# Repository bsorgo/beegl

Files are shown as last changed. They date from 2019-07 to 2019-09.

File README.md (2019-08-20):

# BeeGl

Beehive monitoring system based on _ESP32 based boards_ and _Node Red_.  Main system application is beehive monitoring but can be used also as weather station.

# Main features

- Measures weight, temperature and humidity 
- Outbound communication through WiFi and GPRS (2G)
- Inbound communication using WiFi and Bluetooth (BLE)
- Web based management API - Web GUI and rest
- Pull/push OTA and setting updates
- Node operational time frame rules and power management
- Forms a distributed system where source and broker nodes can be linked together
- Basic server capable of displaying realtime data and statistics



If you like **BeeGl**, give it a star, or fork it and contribute! If you find this system useful please 

## Quick Install

- Broker Device - [README.md](esp32/beegl_broker/README.md)
- Server [README.md](https://github.com/bsorgo/beegl_server)

## Libraries Used

### Broker component

- [ArduinoHTTPClient](https://github.com/arduino-libraries/ArduinoHttpClient) - forked (https://github.com/bsorgo/ArduinoHttpClient) - pending fixes for ESP32 environment
- [ArduinoJson](https://github.com/bblanchon/ArduinoJson)
- [AsyncTcp](https://github.com/me-no-dev/AsyncTCP)
- [DHT sensor library for ESPx](https://github.com/beegee-tokyo/DHTesp)
- [ESP Async WebServer](https://github.com/me-no-dev/ESPAsyncWebServer)
- [HX711](https://github.com/bogde/HX711)
- [PubSubClient](https://github.com/knolleary/pubsubclient)
- [Time](https://github.com/PaulStoffregen/Time) - forked (https://github.com/bsorgo/Time) 
- [Timezone](https://github.com/JChristensen/Timezone)
- [TinyGSM](https://github.com/vshymanskyy)

### Server components

- [Mosquitto](https://mosquitto.org/)
- [Node Red](https://nodered.org/)
- [Node Red Dashboard](https://flows.nodered.org/node/node-red-dashboard)

## License

This program is licensed under GPL-3.0

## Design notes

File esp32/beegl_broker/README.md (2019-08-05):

# BeeGl ESP32 Source/Broker 

## Installing / Getting started

### Hardware
 1. Assemble 
   - build broker /source node device using instructions [BeeGl Beehive Monitoring](https://www.thingiverse.com/thing:3718552) or
   - assemble components on test board using ESP32 board of your choice following [BeeGl Broker/Source Node Schematic](https://thingiverse-production-new.s3.amazonaws.com/assets/a2/c6/a6/41/1a/BeeGl_Broker_rev_1.0.png) or
   - just use any ESP32 board with at least 4MB of flash without components just to play with app
 2. Connect device to serial port using appropriate wiring
### Software
#### From source
 1. Clone repository: git clone https://github.com/bsorgo/beegl.git
 2. Install Platform.IO IDE [PlatformIO IDE](https://platformio.org/platformio-ide?utm_source=github&utm_medium=arduino-esp32)
 3. Run Platform.IO and install Espressif 32 Platform
 4. Open Folder which represents local path of esp32/platformio/beegl_broker
 5. Modify platform.ini [configuration](https://docs.platformio.org/en/latest/platforms/espressif32.html#configuration) `[env:esp32dev]`, `[env:env:lolin_d32_pro_16mb]` 
    or create a new one. In particular `monitor_port` and  `upload_port`should be changed to match assigned local COM port
```
[env:esp32dev_sim800_spiffs]
platform = espressif32
lib_deps = ${common.lib_deps}
board = esp32dev
framework = arduino
board_build.partitions = customparts_tight.csv
upload_port = COM10
monitor_port = COM10
monitor_speed = 115200
build_flags = 
    -DCOMPONENT_EMBED_TXTFILES=src/index.html 
    -DCORE_DEBUG_LEVEL=5
    -DTINY_GSM_MODEM_SIM800
    -DMAX_LOG_FILES=5
    -DMAX_LOG_FILE_SIZE=65536
    -DMQTT_MAX_PACKET_SIZE=512
    -DSYSTEM_VARIANT=\"esp32dev_sim800_spiffs\"
    -DMAX_BACKLOG=200
    -DVER=\"1.1.0\"
```
  6. Upload 
  7. Examine serial output using Monitor 

#### Development/Stable releases

Check [Releases](http://www.github.com/bsorgo/beegl/releases/)

## Runtime

### First run/safe/maintenance mode

At first run or when startup sequence is interrupted by hardware reset/error, device will terminate in safe/maintenance mode. Also indicated by continious red LED. In this case all outbound connections are disabled (WiFi, GPRS) and WiFi access point with SSID: BEE000 and password: 123456789 is brought up. 

Using WiFi capable mobile device establish a connection with SSID named BEE000. 

With web browser on device navigate to http://192.168.4.1 - BeeGl Broker settings page.

The serial output should look something like this:

```
[I][Connection.cpp:133] wifiSetup(): [WIFI] AP started
[I][Connection.cpp:134] wifiSetup(): [WIFI] AP IP: 192.168.4.1
[D][WiFiGeneric.cpp:336] _eventCallback(): Event: 13 - AP_START
[I][Connection.cpp:135] wifiSetup(): [WIFI] AP password: 123456789
[I][Connection.cpp:44] modemOff(): [GSM] OFF
[I][Service.cpp:27] webServerSetup(): [WEB Server] Starting web server
[I][Service.cpp:33] webServerSetup(): [WEB Server] Web server started
[D][Runtime.cpp:223] setSafeModeOnRestart(): [ESP32] Open done
[D][Runtime.cpp:233] setSafeModeOnRestart(): [ESP32] Write fdone.
[D][Runtime.cpp:243] setSafeModeOnRestart(): [ESP32] Commit done.
[I][main.cpp:128] setup(): ***************************************
[I][main.cpp:129] setup(): ******** SAFE/MAINTENANCE MODE ********
[I][main.cpp:130] setup(): ***************************************
[I][main.cpp:131] setup(): Use Wifi device, connect to SSID:BEE000. By using web browser navigate to http://192.168.4.1
```

Note:

On some Android phones mobile data should be disabled when connected to non-internet AP.

### Operational mode

It's normal broker/source node mode. At startup setup sequence is executed:

1. Mount FS filesystem - 1 green LED blink
2. Read config file - 2 green LED blinks
3. Establish inbound/outbound connection and services (web server) - 3 blinks
4. Initiate publisher, sensors and broker - 4 blinks

After setup sequence green LED lights continiously. If any of above steps fails the device goes to deep sleep or safe/maintanance mode.
In addition updates are checked between step 3 and 4 if set accordingly in time interval/frame definition (`"upd" : "true"`)

During main program loop:

- Measurements are performed (weight & temp/humidity)
- Publish measurement to central server
- Check operational time frame and put device in deep sleep

```
[I][Runtime.cpp:41] initialize(): [ESP] Firmware version 1.4
[D][Runtime.cpp:181] getSafeModeOnRestart(): [ESP32] Open done
[D][Runtime.cpp:188] getSafeModeOnRestart(): [ESP32] Read OK, value: 0
[SPIFFS] Begin FS
[D][Runtime.cpp:223] setSafeModeOnRestart(): [ESP32] Open done
[D][Runtime.cpp:233] setSafeModeOnRestart(): [ESP32] Write fdone.
[D][Runtime.cpp:243] setSafeModeOnRestart(): [ESP32] Commit done.
[I][Runtime.cpp:155] printWakeupReason(): [ESP32] Wakeup was not caused by deep sleep. Reason: 0
[I][main.cpp:136] setup(): [ESP] Device name: BEE007
[I][main.cpp:137] setup(): [ESP] Inbound mode: 0
[I][main.cpp:138] setup(): [ESP] Outbound mode: 1
[I][Connection.cpp:90] wifiSetup(): [WIFI] Settings: Use custom ip: 0, IP: 192.168.4.1 GW: 192.168.4.1 NETMASK: 255.255.255.0
[I][Connection.cpp:91] wifiSetup(): [WIFI] APSettings: IP: 192.168.4.1 GW: 0.0.0.0 NETMASK: 255.255.255.0
[I][Connection.cpp:139] wifiSetup(): [WIFI] Starting STA
[I][Connection.cpp:140] wifiSetup(): [WIFI] Outbound connecting to MyWifi
[D][WiFiGeneric.cpp:336] _eventCallback(): Event: 0 - WIFI_READY
[D][WiFiGeneric.cpp:336] _eventCallback(): Event: 2 - STA_START
[D][WiFiGeneric.cpp:336] _eventCallback(): Event: 4 - STA_CONNECTED
[D][WiFiGeneric.cpp:336] _eventCallback(): Event: 7 - STA_GOT_IP
[D][WiFiGeneric.cpp:379] _eventCallback(): STA IP: 192.168.0.163, MASK: 255.255.255.0, GW: 192.168.0.1
[I][Connection.cpp:160] wifiSetup(): [WIFI] connected
[I][Connection.cpp:161] wifiSetup(): [WIFI] IP: 192.168.0.163
[I][Connection.cpp:44] modemOff(): [GSM] OFF
[I][Service.cpp:27] webServerSetup(): [WEB Server] Starting web server
[I][Service.cpp:33] webServerSetup(): [WEB Server] Web server started
[D][Settings.cpp:429] syncTimeAndSettings(): [SETTINGS] Time and setting prefix: www.allium4.com/beegl/
[D][Settings.cpp:434] syncTimeAndSettings(): [SETTINGS] Hostname: www.allium4.com
[D][Settings.cpp:435] syncTimeAndSettings(): [SETTINGS] Path: /beegl/v1/devices/BEE007
[D][Settings.cpp:436] syncTimeAndSettings(): [SETTINGS] Username: bee
[I][Settings.cpp:454] readTimeAndSettings(): [SETTINGS] Response code from server: 200
[I][Settings.cpp:464] readTimeAndSettings(): [SETTINGS] Header date string: Mon, 01 Jul 2019 18:05:21 GMT
[D][Settings.cpp:498] readTimeAndSettings(): [SETTINGS] Time fractions: 2019-07-01T18:05:21.000Z
[D][Settings.cpp:751] getCurrentSchedulerEntry(): [SCHEDULER] Current entry: 7;20:0,20:10;0
[D][Settings.cpp:751] getCurrentSchedulerEntry(): [SCHEDULER] Current entry: 7;20:0,20:10;0
[I][MqttPublisher.cpp:25] setup(): [MQTT] Setup
[I][MqttPublisher.cpp:36] setup(): [MQTT] Server: internalMqttServer
[I][MqttPublisher.cpp:37] setup(): [MQTT] Server: mqtt.allium4.com, port 1883
[I][Measurer.cpp:64] scaleSetup(): [HX711] Setup
[I][Measurer.cpp:65] scaleSetup(): [HX711] Scale factor: -23.209999
[I][Measurer.cpp:66] scaleSetup(): [HX711] Scale offset: 1828191
[I][Measurer.cpp:67] scaleSetup(): [HX711] Scale unit: g
[I][Measurer.cpp:79] dhtSetup(): [DHT] Setup
[D][Runtime.cpp:223] setSafeModeOnRestart(): [ESP32] Open done
[D][Runtime.cpp:233] setSafeModeOnRestart(): [ESP32] Write fdone.
[D][Runtime.cpp:243] setSafeModeOnRestart(): [ESP32] Commit done.
[D][Measurer.cpp:116] measure(): [HX711] Powerup
[D][Measurer.cpp:122] measure(): [MEASURER] Read weight 23451.12
[D][Measurer.cpp:123] measure(): [HX711] Shutdown
[D][Measurer.cpp:131] measure(): [MEASURER] Read temperature and humidity: 23.5 C 65 %
[D][Publisher.cpp:60] storeMessage(): [STORE] Message
[D][MqttPublisher.cpp:74] reconnect(): [MQTTPUBLISHER] Client: BEE007-20, username: bee
[D][MqttPublisher.cpp:77] reconnect(): [MQTTPUBLISHER] Connected.
{"id":"BEE007","time":"2019-07-01T20:05:21+02:00","ver":"1.4","whtS":{"w":23451.12,"u":"g"},"tmpS":{"t":23.5,"u":"C"},"humS":{"h":65,"u":"pct"}}
[D][MqttPublisher.cpp:50] publishMessage(): [MQTTPUBLISHER] scale_sensors
[D][MqttPublisher.cpp:51] publishMessage():
[E][MqttPublisher.cpp:59] publishMessage(): [MQTTPUBLISHER] Publish OK
```

### Settings

Settings can be managed:

- Using web interface on http: `'http://<device ip>`
- Using rest api GET/POST `'http://<device ip>/rest/settings'`



#### Basic settings

1. Device name - Unique device name 
2. Outbound mode. Defines upstream communication preference. For broker node this sets communication with internet/intranet towards central server. For source node this defines communication channel with broker node.
  - Select WiFi if outbound communication is WiFi. Specify Outbound WiFi Settings (SSID, Password and IP related settings)
  - Select GPRS for GPRS communication. Specify Outbound GSM/GPRS Settings (APN, Username and Password). Needles to say SIM card should be inserted in SIM module. These settings are GSM G2 network operator specific. 
3. Setting URL prefix defines central server url in format `<hostname or ip>/<path>/`. Example `192.168.0.250/beegl/`. Currently only http on port 80 is supported. Provide also username and password for basic authentication if required
4. Publisher settings
  - Select MQTT if publisher uses MQTT protocol. Measurements are published on `measurements` topic. 
  - Select HTTP to publish over HTTP. Path is concatenated using Setting URL Prefix and `v1/measurements` path fraction. For example if setting URL prefix is `192.168.0.250/beegl/` measurements resource measurement url is will be published on `192.168.0.250/beegl/v1/measurements`.
 5. MQTT Settings set upstream MQTT server connection parameters
   - Internal server address - MQTT server IP or hostname when outbound connection is WiFi. 
   - External server address - MQTT server IP or hostname when outbound connection is GPRS.
   - Port (TCP Port Number) - MQTT server port. Default port is 1883.
   - Username and password - MQTT server username an password
   Please note MQTT SSL/TLS connections are not supported.
6. Operational Time Intervals are used to define time frames when broker/source node will wake up from deep sleep to operational mode. Specify hour interval From and To in format `hh:mm`. Up to 10 intervals can be specified. Recurring intervals (e.g. wake up every 10 minutes) are not yet supported.

#### Measurement settings
 
 1. Measurer settings:
   - Measure weight (Yes/No)
   - Measure temperature and humidity (Yes/No)
 2. Scale settings
   - Factor (Decimal  number) - a calibration factor
   - Offset (Whole number) - calibration offset. By pressing button __Tare__ this value is determined based on current load. 
   __Measure weight__ button does weight measurement with current calibration factor and offset

 #### Advanced settings
 
1. Inbound mode. Provides inbound channels for other source nodes - when device act as broker:

- None - No inbound connection available
- WiFi - AP Wifi is initiated. Source nodes can connect on broker AP and publish settings based on source node Setting URL prefix to path  `<hostname or ip>/<path>/v1/measurements`
- Bluetooth(BLE) - BT radio and BLE service is established. Used for BLE source nodes. This funcitonality is still under heavy development
- WiFi+Bluetooth(BLE) - both AP WiFi and BLE service are established

2. Refresh (Milliseconds) - refresh interval for measures and publishes. Default 60000 (1 minute).
3. Time settings (Timezone selector). Sets standard and summer timezones.

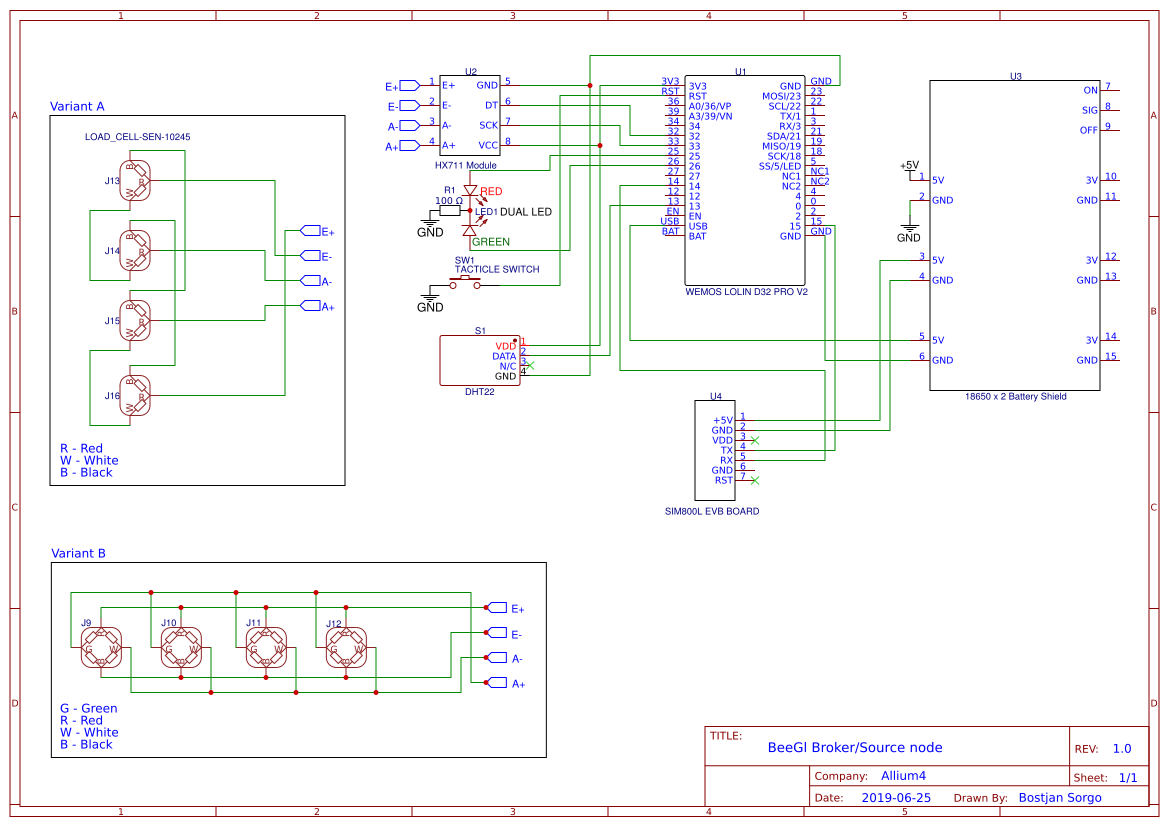
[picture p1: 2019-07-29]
hw/schematic/BeeGl_Broker_LolinD32Pro_SIM800L_rev_1.0.png

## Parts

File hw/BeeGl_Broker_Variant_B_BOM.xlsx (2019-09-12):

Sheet: Info
Name | BeeGL Broker Variant B BOM Rev 1.0
Sheets
LolinD32-ESP32 | Bill of material for Lolin D32 ProESP32 board & SIM800L 3G GSM/GPRS module part. Used only for Wifi Outbound/Inbound Communication
LolinD32-ESP32-SIM800L | Bill of material for Lolin D32 Pro ESP32 board 3G GSM/GPRS module part. Used for GSM or/and Wifi Outbound/Inbound Communication
Load Cells Frame | Bill of material for load sensor frame
Supplemental material
 | Instant glue (Superglue, Loctite, Gorilla,…) to assemble plastic parts together
 | Solder & solder paste to connect wires/components/connectors
Release notes
2019-08-28 | Initial release

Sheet: LolinD32-ESP32
ID | Component came | Designator | Quantity | Unit | More info/Query | Note
1 | WEMOS LOLIN D32 PRO V2 | U1 | 1 | pcs | https://wiki.wemos.cc/products:d32:d32_pro
2 | HX711 Module | U2 | 1 | pcs | https://www.google.com/search?q=hx711+module https://www.sparkfun.com/products/13879 https://www.aliexpress.com/wholesale?catId=0&initiative_id=SB_20190705010449&SearchText=hx711
3 | 18650 x 2 Battery Shield | U3 | 1 | pcs | https://www.aliexpress.com/wholesale?catId=0&initiative_id=SB_20190705011301&SearchText=battery+shield
4 | DHT22 | S1 | 1 | pcs | https://www.google.com/search?q=dht22
5 | DUAL LED | LED1 | 1 | pcs | https://www.google.com/search?q=dual+led+3mm+green+red
6 | 100 Ω | R1 | 1 | pcs
7 | TACTICLE SWITCH | SW1 | 1 | pcs | https://www.google.com/search?q=tacticle+switch
8 | Heat shrink tube 1.5 mm (1/16) |  | 1 | m | Used for cable to cable or cable to component contacts
9 | Heat shrink tube 1.5 mm (1/8) |  | 1 | m | Used for cable to cable or cable to component contacts
10 | Heat shrink tube 1.5 mm (1/4) |  | 1 | m | Used for cable to cable or cable to component contacts
11 | Dupont 1P 10 cm Female to Female |  | 20 | pcs | https://www.google.com/search?q=dupont+female+to+female+10+cm&oq=dupont+female+to+female+10+cm
12 | Nylon M3 6mm stadoff with screw |  | 6 | pcs | https://www.google.com/search?q=M3+Nylon+screw+standoff
13 | 18650 2000mAh Battery |  | 2 | pcs
14 | M5x20 Hexagon socket Head Cap Screw |  | 2 | pcs | ISO 4762, A2 Stainless steel, Hexagon/Torx socket head cap screw, k=5mm, l=20mm http://www.fasteners.eu/standards/ISO/4762
15 | M5x10 Hexagon socket Head Cap Screw |  | 2 | pcs | ISO 4762, A2 Stainless steel, Hexagon/Torx socket head cap screw, k=5mm, l=10mm http://www.fasteners.eu/standards/ISO/4762
16 | M5 Hexagon Nut |  | 4 | pcs | ISO 4032, A2 Stainless steel Hexagon nut, m=~4.5, s=8 http://www.fasteners.eu/standards/ISO/4032
17 | Pre/Post paid subscirpiton Micro SIM - 2G/GPRS Data Eligible |  | 1 | pcs
18 | Lolin D 32 Pro Case |  | 1 | pcs | 3D printed beegl_broker_variant_B_lolind32pro_dual_18650_case.stl | Recommended ASA material, >40% infill density
19 | Case cover |  | 1 | pcs | 3D printed beegl_broker_case_cover_no_holes.stl | Recommended ASA material, >60% infill density
20 | Mounting panel |  | 1 | pcs | 3D printed beegl_broker_mounting_panel.stl | Recommended ASA material, >60% infill density
21 | Solar panel holder broker case mount |  | 1 | pcs | 3D printed beegl_broker_solar_panel_holder_beegl_broker_mount.stl | Recommended ASA material, >60% infill density
22 | Solar panel holder solar panel mount |  | 1 | pcs | 3D printed beegl_broker_solar_panel_holder_solar_panel_mount.stl | Recommended ASA material, >60% infill density
23 | 5V USB Solar panel |  | 1 | pcs | Solar panel, output voltage 5V, USB female connector and at least 5W. https://www.aliexpress.com/item/33023060443.html
24 | Micro usb cable |  | 1 | pcs | 20 or 30 cm usb cable (depends on solar panel model)

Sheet: LolinD32-ESP32-SIM800L
ID | Component came | Designator | Quantity | Unit | More info/Query | Note
1 | WEMOS LOLIN D32 PRO V2 | U1 | 1 | pcs | https://wiki.wemos.cc/products:d32:d32_pro
2 | HX711 Module | U2 | 1 | pcs | https://www.google.com/search?q=hx711+module https://www.sparkfun.com/products/13879 https://www.aliexpress.com/wholesale?catId=0&initiative_id=SB_20190705010449&SearchText=hx711
3 | 18650 x 2 Battery Shield | U3 | 1 | pcs | https://www.aliexpress.com/wholesale?catId=0&initiative_id=SB_20190705011301&SearchText=battery+shield
4 | DHT22 | S1 | 1 | pcs | https://www.google.com/search?q=dht22
5 | DUAL LED | LED1 | 1 | pcs | https://www.google.com/search?q=dual+led+3mm+green+red
6 | 100 Ω | R1 | 1 | pcs
7 | TACTICLE SWITCH | SW1 | 1 | pcs | https://www.google.com/search?q=tacticle+switch
8 | Heat shrink tube 1.5 mm (1/16) |  | 1 | m | Used for cable to cable or cable to component contacts
9 | Heat shrink tube 1.5 mm (1/8) |  | 1 | m | Used for cable to cable or cable to component contacts
10 | Heat shrink tube 1.5 mm (1/4) |  | 1 | m | Used for cable to cable or cable to component contacts
11 | Dupont 1P 10 cm Female to Female |  | 20 | pcs | https://www.google.com/search?q=dupont+female+to+female+10+cm&oq=dupont+female+to+female+10+cm
12 | Nylon M3 6mm stadoff with screw |  | 6 | pcs | https://www.google.com/search?q=M3+Nylon+screw+standoff
13 | 18650 2000mAh Battery |  | 2 | pcs
14 | M5x20 Hexagon socket Head Cap Screw |  | 2 | pcs | ISO 4762, A2 Stainless steel, Hexagon/Torx socket head cap screw, k=5mm, l=20mm http://www.fasteners.eu/standards/ISO/4762
15 | M5x10 Hexagon socket Head Cap Screw |  | 2 | pcs | ISO 4762, A2 Stainless steel, Hexagon/Torx socket head cap screw, k=5mm, l=10mm http://www.fasteners.eu/standards/ISO/4762
16 | M5 Hexagon Nut |  | 4 | pcs | ISO 4032, A2 Stainless steel Hexagon nut, m=~4.5, s=8 http://www.fasteners.eu/standards/ISO/4032
17 | Pre/Post paid subscirpiton Micro SIM - 2G/GPRS Data Eligible |  | 1 | pcs
18 | Lolin D 32 Pro and SIM800L Case |  | 1 | pcs | 3D printed beegl_broker_variant_B_lolind32pro_sim800l_dual_18650_case.stl | Recommended ASA material, >40% infill density
19 | Case cover |  | 1 | pcs | 3D printed beegl_broker_case_cover_no_holes.stl | Recommended ASA material, >60% infill density
20 | Mounting panel |  | 1 | pcs | 3D printed beegl_broker_mounting_panel.stl | Recommended ASA material, >60% infill density
21 | Solar panel holder broker case mount |  | 1 | pcs | 3D printed beegl_broker_solar_panel_holder_beegl_broker_mount.stl | Recommended ASA material, >60% infill density
22 | Solar panel holder solar panel mount |  | 1 | pcs | 3D printed beegl_broker_solar_panel_holder_solar_panel_mount.stl | Recommended ASA material, >60% infill density
23 | SIM800L EVB BOARD | U4 | 1 | pcs | https://www.google.com/search?q=sim800l+v2.0 https://www.aliexpress.com/wholesale?SearchText=sim800l+v2.0
24 | Nylon M3 10mm stadoff with screw |  | 2 | pcs | https://www.google.com/search?q=M3+Nylon+screw+standoff
25 | GSM antena |  | 1 | pcs | 868/915/1800/1900 MHz SMA Male antenna 2, 3 or 5 DBI. To choose depending on signal strenght & local compliancy. With SMA male connector.
26 | GSM antenna SMA to U-FL cable 10 cm |  | 1 | pcs | SMA female to U.FL connector 10 cm https://www.google.com/search?q=SMA+to+U.FL
26 | 5V USB Solar panel |  | 1 | pcs | Solar panel, output voltage 5V, USB female connector and at least 5W. https://www.aliexpress.com/item/33023060443.html
27 | Micro usb cable |  | 1 | pcs | 20 or 30 cm usb cable (depends on solar panel USB connector distance)

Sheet: Load Cells Frame
ID | Component came | Designator | Quantity | Unit | More info/Query | Note
1 | AlMgSi 20x20x2 U-Profile B1 |  | 2 | pcs | BeeGl_Broker_VariantB_Drawings_rev_1.1.pdf
2 | AlMgSi 20x20x2 U-Profile A1 |  | 1 | pcs | BeeGl_Broker_VariantB_Drawings_rev_1.1.pdf
3 | AlMgSi 20x20x2 U-Profile A2 |  | 1 | pcs | BeeGl_Broker_VariantB_Drawings_rev_1.1.pdf
4 | Straight Bar Load Cell Bottom Edge |  | 4 | pcs | 3D printed beegl_broker_variant_B_almgsi_20x20x2_straight_bar_load_cell_bottom_edge.stl | Recommended ASA material, >60% infill density
5 | Straight Bar Load Cell Top Edge |  | 4 | pcs | 3D printed beegl_broker_variant_B_almgsi_20x20x2_straight_bar_load_cell_top_edge.stl (https://www.google.com/search?q=dht22) | Recommended ASA material, >60% infill density
6 | Straight Bar Load Cell Base |  | 1 | pcs | 3D printed beegl_broker_variant_B_almgsi_20x20x2_straight_bar_load_cell_base.stl (https://www.google.com/search?q=dual+led+3mm+green+red) | Recommended ASA material, >60% infill density
7 | Cable align |  | 8 | pcs | 3D printed beegl_broker_variant_B_almgsi_20x20x2_straight_bar_load_cell_cable_align.stl | Recommended ASA material, >60% infill density
8 | M5x20 Countesunk Head Cap Screw |  | 8 | pcs | ISO 10642,A2 Stainless steel, Hexagon/Torx socket countersunk head cap screw, k=5mm, l=20mm http://www.fasteners.eu/standards/ISO/10642
9 | M5x15 Countesunk Head Cap Screw |  | 8 | pcs | ISO 10642,A2 Stainless steel, Hexagon/Torx socket countersunk head cap screw, k=5mm, l=15mm http://www.fasteners.eu/standards/ISO/10642
10 | M4x10 Countesunk Head Cap Screw |  | 10 | pcs | ISO 10642,A2 Stainless steel, Hexagon/Torx socket countersunk head cap screw, k=4mm, l=10mm http://www.fasteners.eu/standards/ISO/10642
11 | M5 Hexagon Nut |  | 8 | pcs | ISO 4032, A2 Stainless steel Hexagon nut M5, m=~4.5, s=8 http://www.fasteners.eu/standards/ISO/4032
12 | M4 Hexagon Nut |  | 2 | pcs | ISO 4032, A2 Stainless steel Hexagon nut M4, m=~4, s=7 http://www.fasteners.eu/standards/ISO/4032
13 | FTP patch cable |  | 2 | m | Soft cable. Outer insulation removed. Only twisted pair wires used to prolong load cell & dht22 wires | Can be replaced with single or twisted pair copper wire/cable of diameter 0.1~0.16mm
14 | LOAD_CEL-20KG | J9,J10,J11,J12 | 4 | pcs | https://www.google.com/search?&q=load+cell+20kg https://www.aliexpress.com/wholesale?catId=0&initiative_id=SB_20190705010547&SearchText=load+cell https://www.banggood.com/search/load-cell.html
15 | 2.54 Pitch 1P Housing with Female Terminal Sockets |  | 10 | pcs | 2.54mm Pitch 1P Dupont Jumper Wire Housing with 50x Female Dupont Terminal Sockets

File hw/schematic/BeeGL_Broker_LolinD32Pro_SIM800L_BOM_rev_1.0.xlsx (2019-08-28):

ID | Name | Designator | Footprint | Quantity | More info/Query | Note
1 | WEMOS LOLIN D32 PRO V2 | U1 | WEMOS_LOLIN_D32_PRO | 1 | https://wiki.wemos.cc/products:d32:d32_pro
2 | HX711 Module | U2 | NONE | 1 | https://www.google.com/search?q=hx711+module https://www.sparkfun.com/products/13879 https://www.aliexpress.com/wholesale?catId=0&initiative_id=SB_20190705010449&SearchText=hx711
3 | 18650 x 2 Battery Shield | U3 | 18650 X 2 BATTERY SHIELD V8 | 1 | https://www.aliexpress.com/wholesale?catId=0&initiative_id=SB_20190705011301&SearchText=battery+shield
4 | SIM800L EVB BOARD | U4 | HDR1X6_SIM800L_BOARD | 1 | https://www.google.com/search?q=sim800l+v2.0 https://www.aliexpress.com/wholesale?SearchText=sim800l+v2.0
5 | DHT22 | S1 | DHT22 | 1 | https://www.google.com/search?q=dht22
6 | DUAL LED | LED1 | LED-3MM_DUAL | 1 | https://www.google.com/search?q=dual+led+3mm+green+red
7 | 100 Ω | R1 | NONE | 1
8 | TACTICLE SWITCH | SW1 | KEY-6.0*6.0-4 | 1 | https://www.google.com/search?q=tacticle+switch
9 | LOAD_CEL-20KG | J9,J10,J11,J12 | 1X03 | 4 | https://www.google.com/search?&q=load+cell+20kg https://www.aliexpress.com/wholesale?catId=0&initiative_id=SB_20190705010547&SearchText=load+cell https://www.banggood.com/search/load-cell.html | Variant B,C
10 | LOAD_CELL-SEN-10245 | J13,J14,J15,J16 | 1X03 | 4 | https://www.google.com/search?&q=load+cell+50kg https://www.sparkfun.com/products/10245 | Variant A

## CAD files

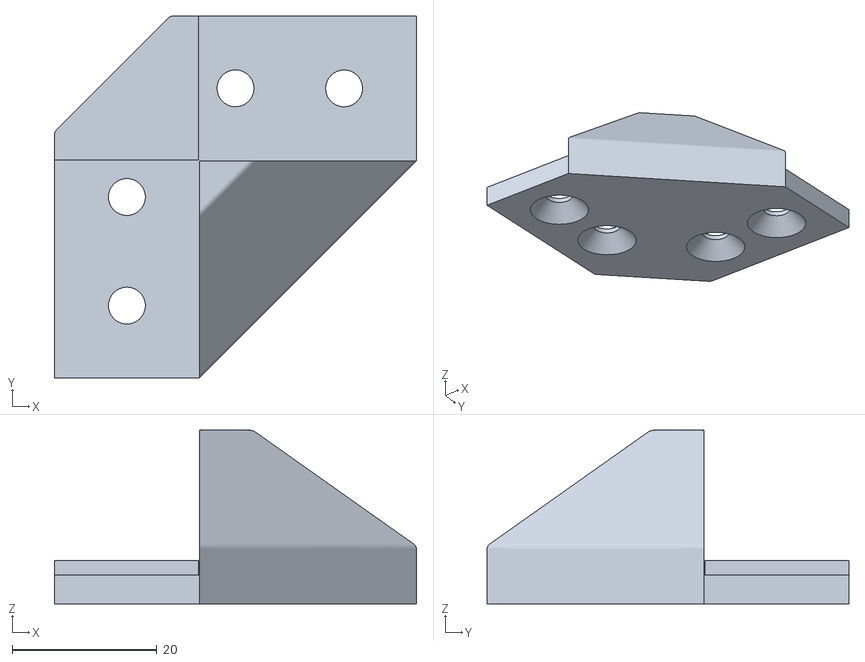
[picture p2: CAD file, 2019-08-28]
hw/3D_models/beegl_broker_variant_B_almgsi_20x20x2_straight_bar_load_cell_top_edge.stl
50.0 x 50.0 x 24.0

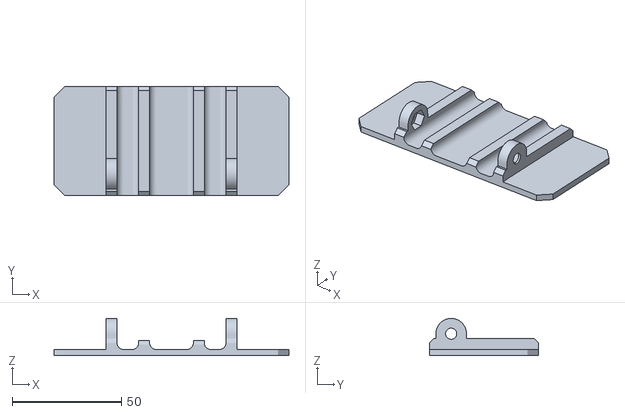
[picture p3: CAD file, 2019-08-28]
hw/3D_models/beegl_broker_solar_panel_holder_solar_panel_mount.stl
107.4 x 50.0 x 17.0

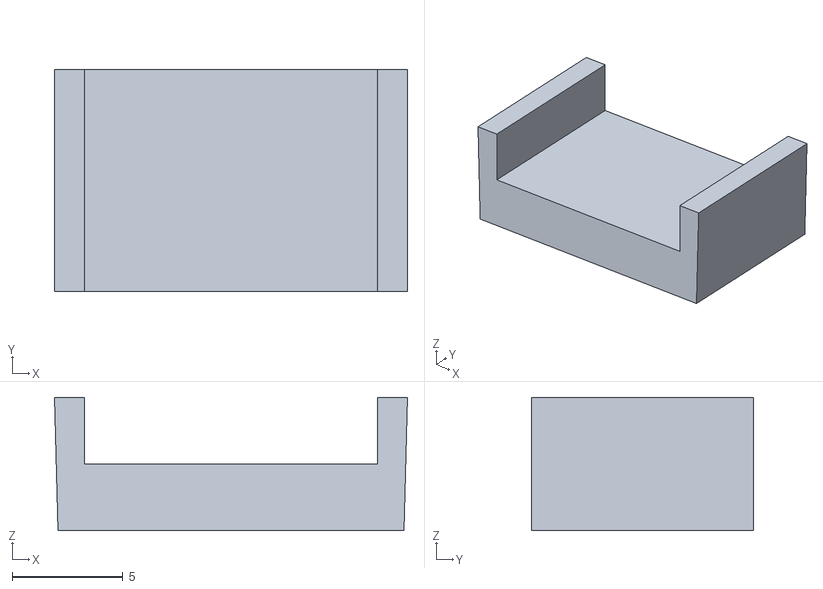
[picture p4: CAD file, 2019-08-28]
hw/3D_models/beegl_broker_variant_B_almgsi_20x20x2_straight_bar_load_cell_cable_align.stl
15.9 x 10.0 x 6.00

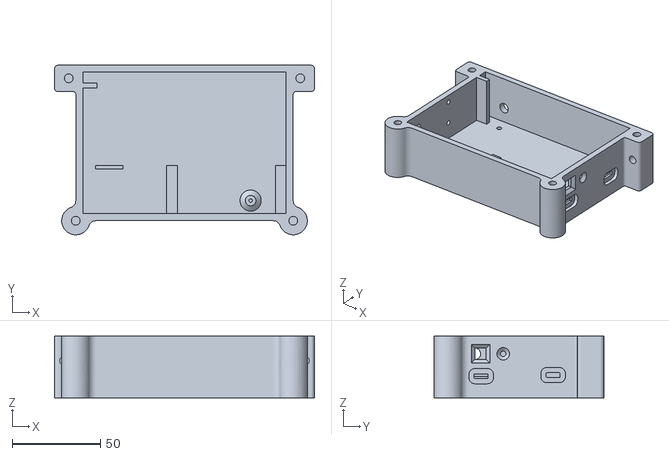
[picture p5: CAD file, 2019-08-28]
hw/3D_models/beegl_broker_variant_B_lolind32pro_sim800l_dual_18650_case.stl
147.1 x 96.0 x 35.0

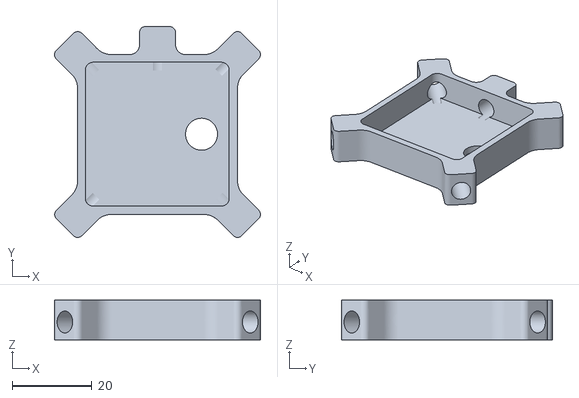
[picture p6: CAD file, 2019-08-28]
hw/3D_models/beegl_broker_variant_A_hx711_dht22_case.stl
51.5 x 52.7 x 10.00

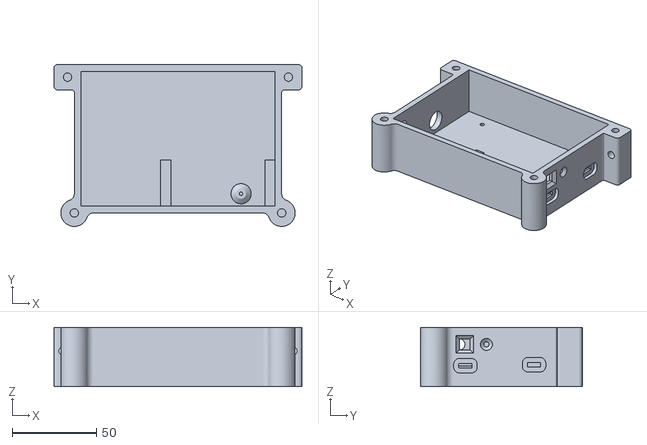
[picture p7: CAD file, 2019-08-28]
hw/3D_models/beegl_broker_variant_AC_lolind32pro_sim800l_dual_18650_case.stl
147.1 x 96.0 x 35.0

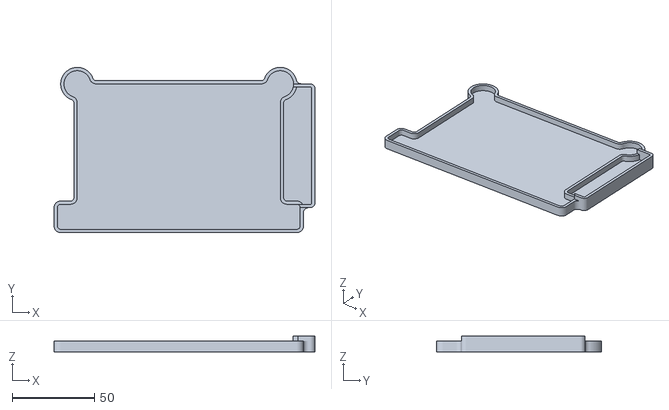
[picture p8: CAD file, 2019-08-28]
hw/3D_models/beegl_broker_case_cover_no_holes.stl
158.2 x 100.2 x 9.40

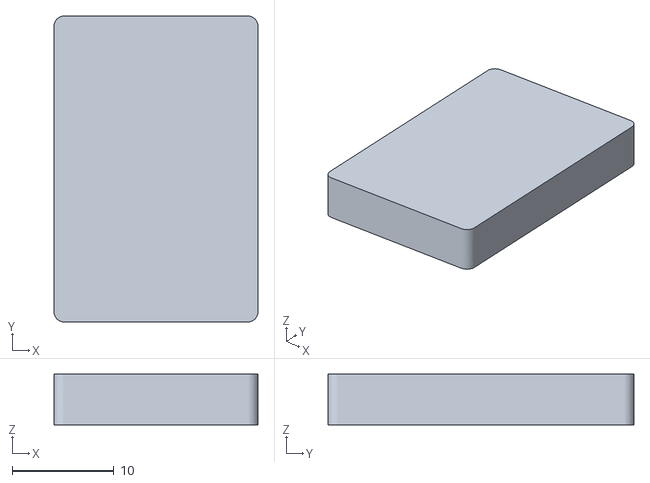
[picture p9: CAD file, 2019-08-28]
hw/3D_models/beegl_broker_variant_BC_almgsi_20x20x2_straight_bar_load_cell_top_dist_wo_holes.stl
20.0 x 30.0 x 5.00

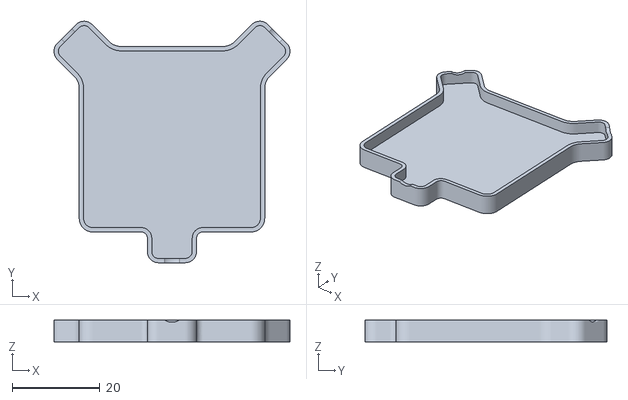
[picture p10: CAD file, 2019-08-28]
hw/3D_models/beegl_broker_variant_C_hx711_dht22_case_cover.stl
53.7 x 54.9 x 5.00

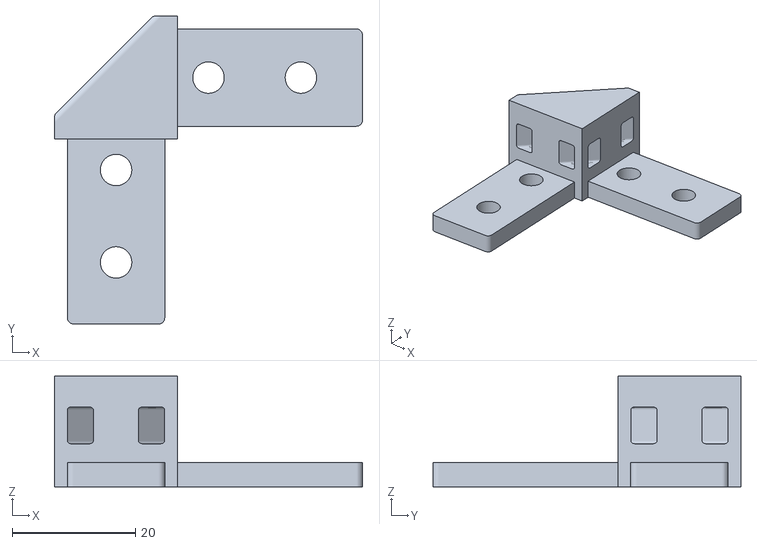
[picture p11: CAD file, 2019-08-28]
hw/3D_models/beegl_broker_variant_B_almgsi_20x20x2_straight_bar_load_cell_bottom_edge.stl
50.0 x 50.0 x 18.0

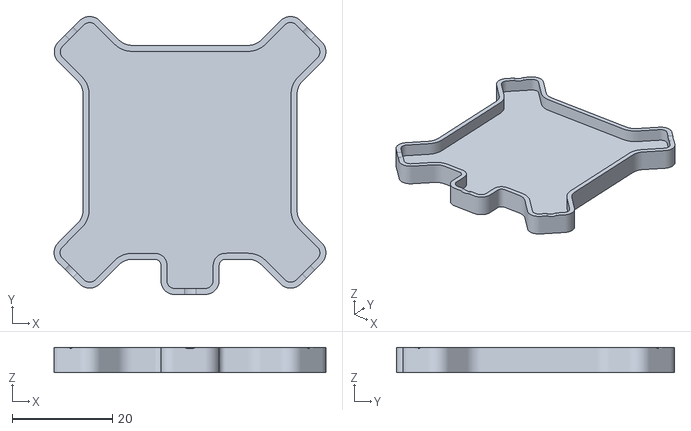
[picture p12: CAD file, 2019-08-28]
hw/3D_models/beegl_broker_variant_A_hx711_dht22_case_cover.stl
54.1 x 55.3 x 5.00

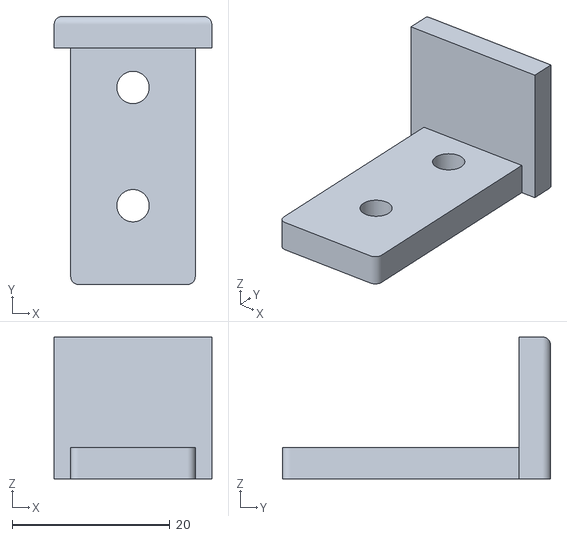
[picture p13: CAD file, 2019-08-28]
hw/3D_models/beegl_broker_variant_BC_almgsi_20x20x2_straight_bar_load_cell_dist_20mm.stl
20.0 x 34.0 x 18.0

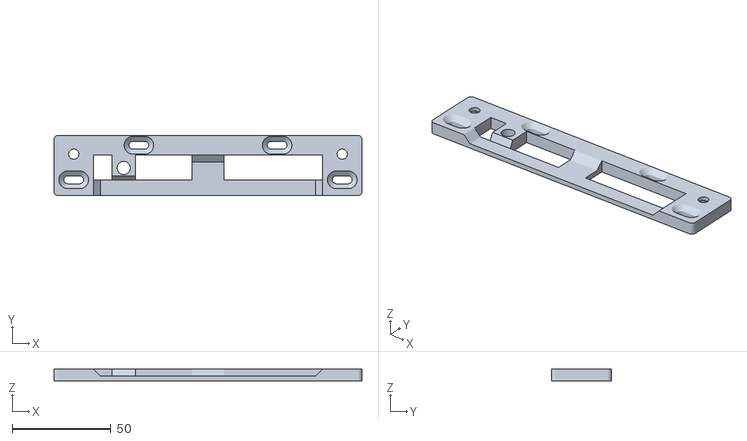
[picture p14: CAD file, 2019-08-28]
hw/3D_models/beegl_broker_mounting_panel.stl
156.0 x 30.5 x 6.00

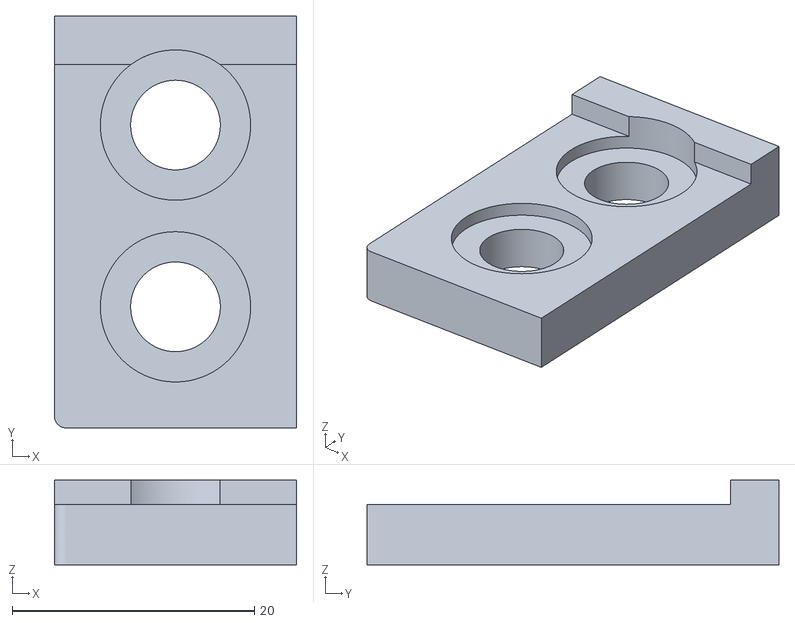
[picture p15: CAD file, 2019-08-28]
hw/3D_models/beegl_broker_variant_C_almgsi_20x20x2_straight_bar_load_cell_top_dist_w_holes.stl
20.0 x 34.0 x 7.00

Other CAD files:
hw/3D_models/beegl_broker_variant_B_lolind32pro_dual_18650_case.stl
hw/3D_models/beegl_broker_solar_panel_holder_beegl_broker_mount.stl
hw/3D_models/beegl_broker_variant_C_hx711_dht22_case.stl
hw/3D_models/beegl_broker_variant_B_almgsi_20x20x2_straight_bar_load_cell_base.stl
hw/3D_models/beegl_broker_case_cover.stl
hw/3D_models/beegl_broker_variant_A_load_cell_holder.stl

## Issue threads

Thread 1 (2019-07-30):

Persistent log

bsorgo, 2019-07-30:
**Is your feature request related to a problem? Please describe.**

After installed broker units being operational for some days some units stopped delivering measurements due to unknown reasons.

A need to have some kind of trace/info/debug information about past events is essential to diagnose and resolve issue and/or eventually provide software or hardware improvements.

**Describe the solution you'd like**

All relevant log entries according to set log level  outputed to stdout should be also persistanted in storage file. If HW  supports SD card this storage should be the best solution, otherwise SPIFFS can be used.
Since flash/SD card storage is limited, has finite write cycles and it is slow it's imperative to:

- keep impact on operational mode as low as possible (peformance, I/O)
- limit the amount of storage dedicated to log
- prevent frequent file overwrites using file rotation

When device is in operational or maintenance/safe mode log files should be obtainable through GUI/API:

- get a list of available log files - filenames
- get log file content
- remove log file(s)

Closed 2019-08-03.

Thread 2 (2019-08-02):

Persistent measurements

bsorgo, 2019-08-02:
**Is your feature request related to a problem? Please describe.**

During broker operation a measurment publish may fail. This cause measurements not being published and may be lost after devices goes to deep sleep/reset. Current implementation supports only in memory short term persistance.

**Describe the solution you'd like**

Readings should be preserved in SPIFFS/SD storage when publish fails. On next publish cycle backlog readings should be published.

All activities should be properly logged.

Closed 2019-08-03.

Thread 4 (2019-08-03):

Setting file fallback

bsorgo, 2019-08-03:
**Is your feature request related to a problem? Please describe.**

It may happen settings files gets corrupted. In current implementation setting file is created/replaced from default (code) values.

**Describe the solution you'd like**

Settings should be loaded using this alghoritm:

- if config file fails to load/parse fallback to last good config. Last good config is created on sucessful boot (copy config->last good)
- if last good fails to load/parse fallback to backup config. Backup config is created every time when setting file is saved
- if backup fails to load/parse fallback to default SPIFFS config. Default config might be uploaded by factory defaults and can contain minimum configuration required to bring device up.
- if default config fails restore config file from default, code values

Closed 2019-08-03.

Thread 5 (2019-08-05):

PS ram build flags

bsorgo, 2019-08-05:
**Describe the bug**
A platformio.ini has invalid build flag spec for PS ram boards
```
-DBOARD_HAS_PSRAM -mfix-esp32-psram-cache-issue
```
**Expected behavior**
Correct build flag spec:
```
-DBOARD_HAS_PSRAM
-mfix-esp32-psram-cache-issue
```

Closed 2019-09-12.

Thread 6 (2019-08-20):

LoRaWAN support

bsorgo, 2019-08-20:
**Is your feature request related to a problem? Please describe.**

Currently only GPRS (2G) is supported for distant brokers. It's well known fact 2G network is subject of deprecation in many countries. An alternative low power and resource consumption should be provided.

**Describe the solution you'd like**

Add support for LoRaWAN.

https://lora-alliance.org/about-lorawan

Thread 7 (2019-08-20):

NB-IoT support

bsorgo, 2019-08-20:
Is your feature request related to a problem? Please describe.

Currently only GPRS (2G) is supported for distant brokers. It's well known fact 2G network is subject of deprecation in many countries. An alternative low power and resource consumption should be provided.

Describe the solution you'd like

Add support for NB-IoT for message publishing.

https://en.wikipedia.org/wiki/Narrowband_IoT

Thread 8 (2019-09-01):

Inconsistent weight measures

bsorgo, 2019-09-01:
**Describe the bug**

When device does first measure after powerup the value deviates compared to subsequent measurements

Example from device BEE005:
```
...
{
        "_id": "5d6b4488a8313354cf041e98",
        "time": "2019-09-01T04:09:34.000Z",
        "deviceId": "BEE005",
        "ver": "1.1.0",
        "weight": 63591.25,
        "weightUnit": "g",
        "temperature": 22.4,
        "temperatureUnit": "C",
        "humidity": 69.8,
        "humidityUnit": "pct"
    },
    {
        "_id": "5d6b44cea8313354cf041e9b",
        "time": "2019-09-01T04:10:44.000Z",
        "deviceId": "BEE005",
        "ver": "1.1.0",
        "weight": 63588.89,
        "weightUnit": "g",
        "temperature": 22.4,
        "temperatureUnit": "C",
        "humidity": 69.5,
        "humidityUnit": "pct"
    },
    {
        "_id": "5d6b5ea9a8313354cf041ee2",
        "time": "2019-09-01T06:01:03.000Z",
        "deviceId": "BEE005",
        "ver": "1.1.0",
        "weight": 63873.48,
        "weightUnit": "g",
        "temperature": 22.5,
        "temperatureUnit": "C",
        "humidity": 69.8,
        "humidityUnit": "pct"
    },
    {
        "_id": "5d6b5ef2a8313354cf041ee5",
        "time": "2019-09-01T06:02:14.000Z",
        "deviceId": "BEE005",
        "ver": "1.1.0",
        "weight": 63516.91,
        "weightUnit": "g",
        "temperature": 23.6,
        "temperatureUnit": "C",
        "humidity": 63.9,
        "humidityUnit": "pct"
    },
    {
        "_id": "5d6b5f39a8313354cf041ee8",
        "time": "2019-09-01T06:03:27.000Z",
        "deviceId": "BEE005",
        "ver": "1.1.0",
        "weight": 63502.95,
        "weightUnit": "g",
        "temperature": 23.6,
        "temperatureUnit": "C",
        "humidity": 70.2,
        "humidityUnit": "pct"
    },
    {
        "_id": "5d6b5f7fa8313354cf041eeb",
        "time": "2019-09-01T06:04:37.000Z",
        "deviceId": "BEE005",
        "ver": "1.1.0",
        "weight": 63494.89,
        "weightUnit": "g",
        "temperature": 23.6,
        "temperatureUnit": "C",
        "humidity": 70.6,
        "humidityUnit": "pct"
    },
...
```
Example from device BEE006:

```
 {
        "_id": "5d6b607ca8313354cf041ef5",
        "time": "2019-09-01T06:08:51.000Z",
        "deviceId": "BEE006",
        "ver": "1.2.0",
        "weight": 2406.724,
        "weightUnit": "g",
        "temperature": 22.6,
        "temperatureUnit": "C",
        "humidity": 99.9,
        "humidityUnit": "pct"
    },
    {
        "_id": "5d6b60c2a8313354cf041ef8",
        "time": "2019-09-01T06:10:00.000Z",
        "deviceId": "BEE006",
        "ver": "1.2.0",
        "weight": 2391.526,
        "weightUnit": "g",
        "temperature": 22.8,
        "temperatureUnit": "C",
        "humidity": 99.9,
        "humidityUnit": "pct"
    },
    {
        "_id": "5d6b7abea8313354cf041f43",
        "time": "2019-09-01T08:00:42.000Z",
        "deviceId": "BEE006",
        "ver": "1.2.0",
        "weight": 7093.706,
        "weightUnit": "g",
        "temperature": 23,
        "temperatureUnit": "C",
        "humidity": 99.9,
        "humidityUnit": "pct"
    },
    {
        "_id": "5d6b7b05a8313354cf041f46",
        "time": "2019-09-01T08:02:01.000Z",
        "deviceId": "BEE006",
        "ver": "1.2.0",
        "weight": 2095.978,
        "weightUnit": "g",
        "temperature": 28.9,
        "temperatureUnit": "C",
        "humidity": 77.4,
        "humidityUnit": "pct"
    },
    {
        "_id": "5d6b7b4ba8313354cf041f49",
        "time": "2019-09-01T08:03:13.000Z",
        "deviceId": "BEE006",
        "ver": "1.2.0",
        "weight": 2090.39,
        "weightUnit": "g",
        "temperature": 28.8,
        "temperatureUnit": "C",
        "humidity": 83.1,
        "humidityUnit": "pct"
    },
```

**To Reproduce**
Steps to reproduce the behavior:
1. Powerup device
2. Check measurments.

**Expected behavior**

Reading should be consistent.

Closed 2019-09-12.

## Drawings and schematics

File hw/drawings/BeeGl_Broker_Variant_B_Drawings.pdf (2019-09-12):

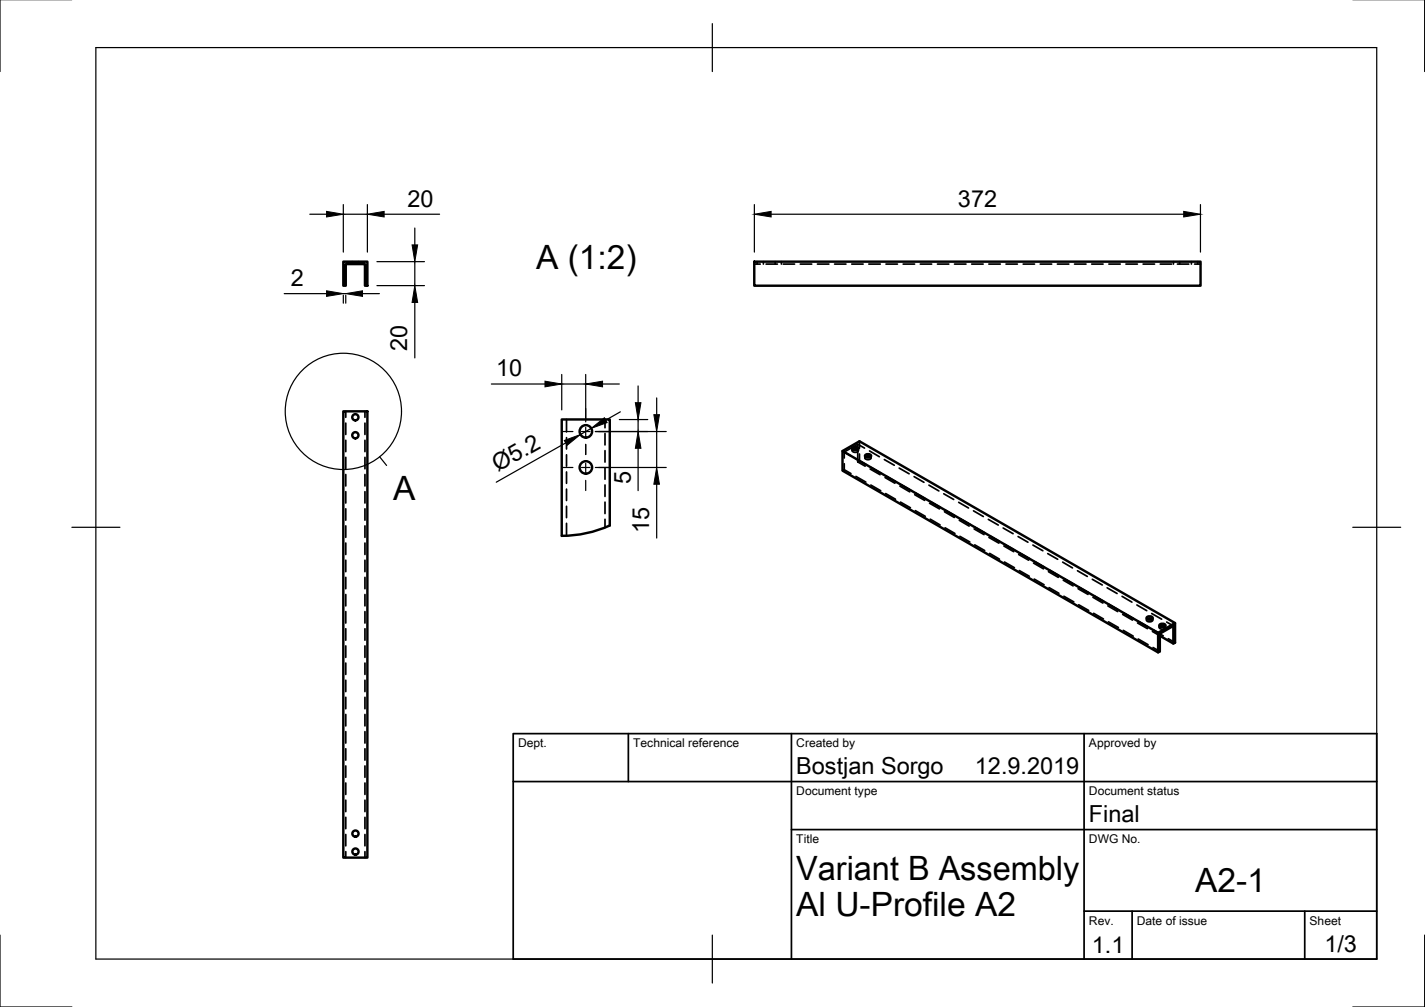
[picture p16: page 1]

Dept. | Technical reference | Created by Bostjan Sorgo 12.9.2019 | Approved by

Document type | Document status Final

Title Al U-Profile A2 | DWG No. A2-1 Variant B Assembly

Rev. | Date of issue | Sheet

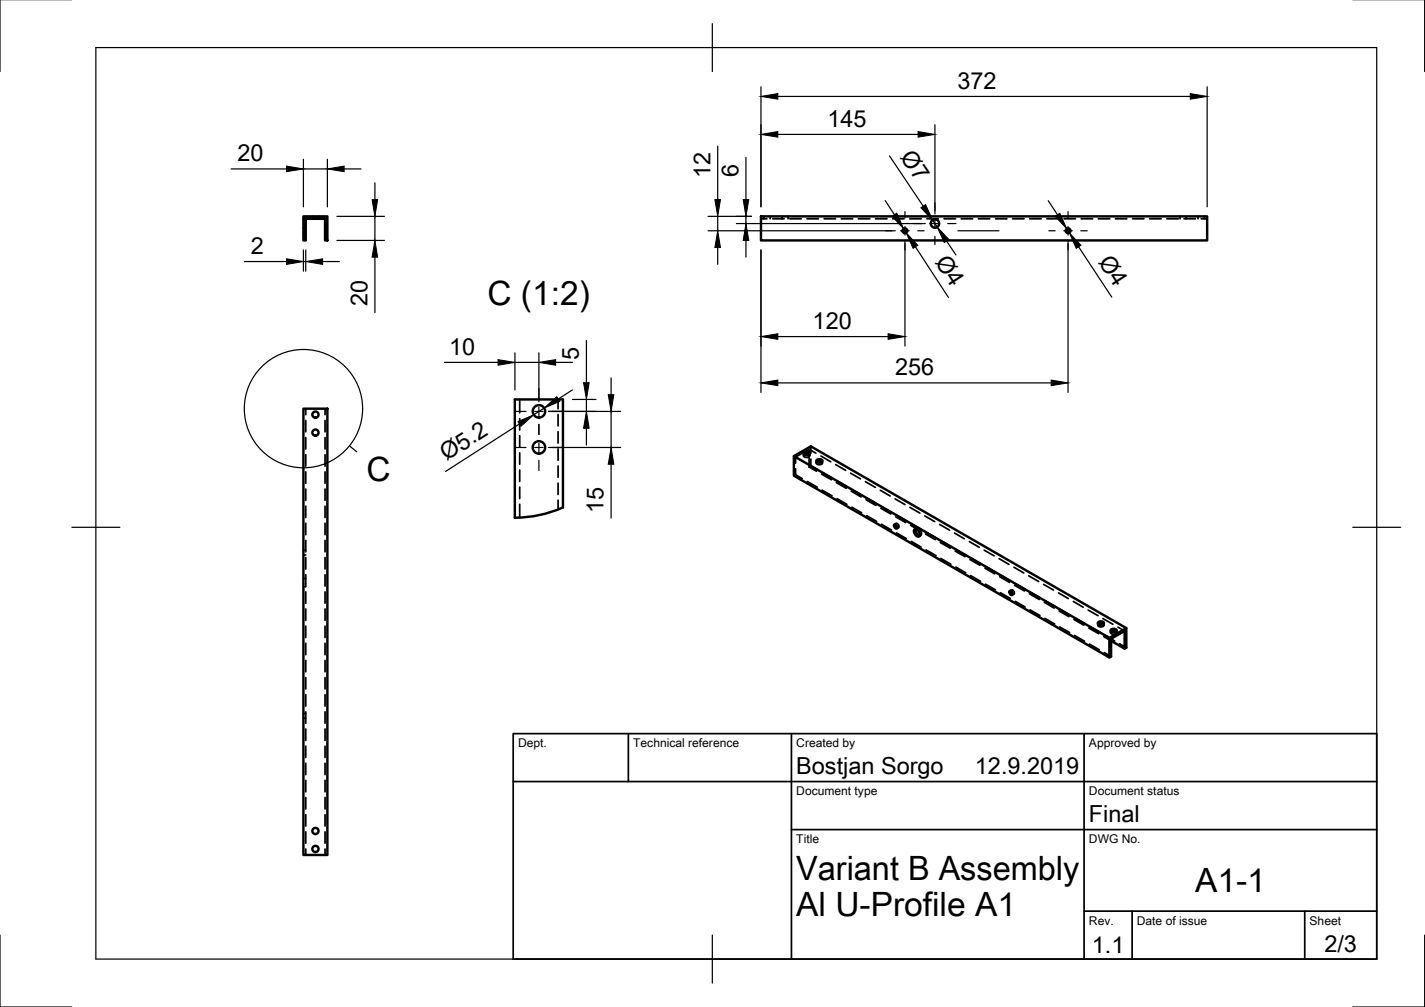
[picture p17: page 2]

Dept. | Technical reference | Created by Bostjan Sorgo 12.9.2019 | Approved by

Document type | Document status Final

Title Al U-Profile A1 | DWG No. A1-1 Variant B Assembly

Rev. | Date of issue | Sheet

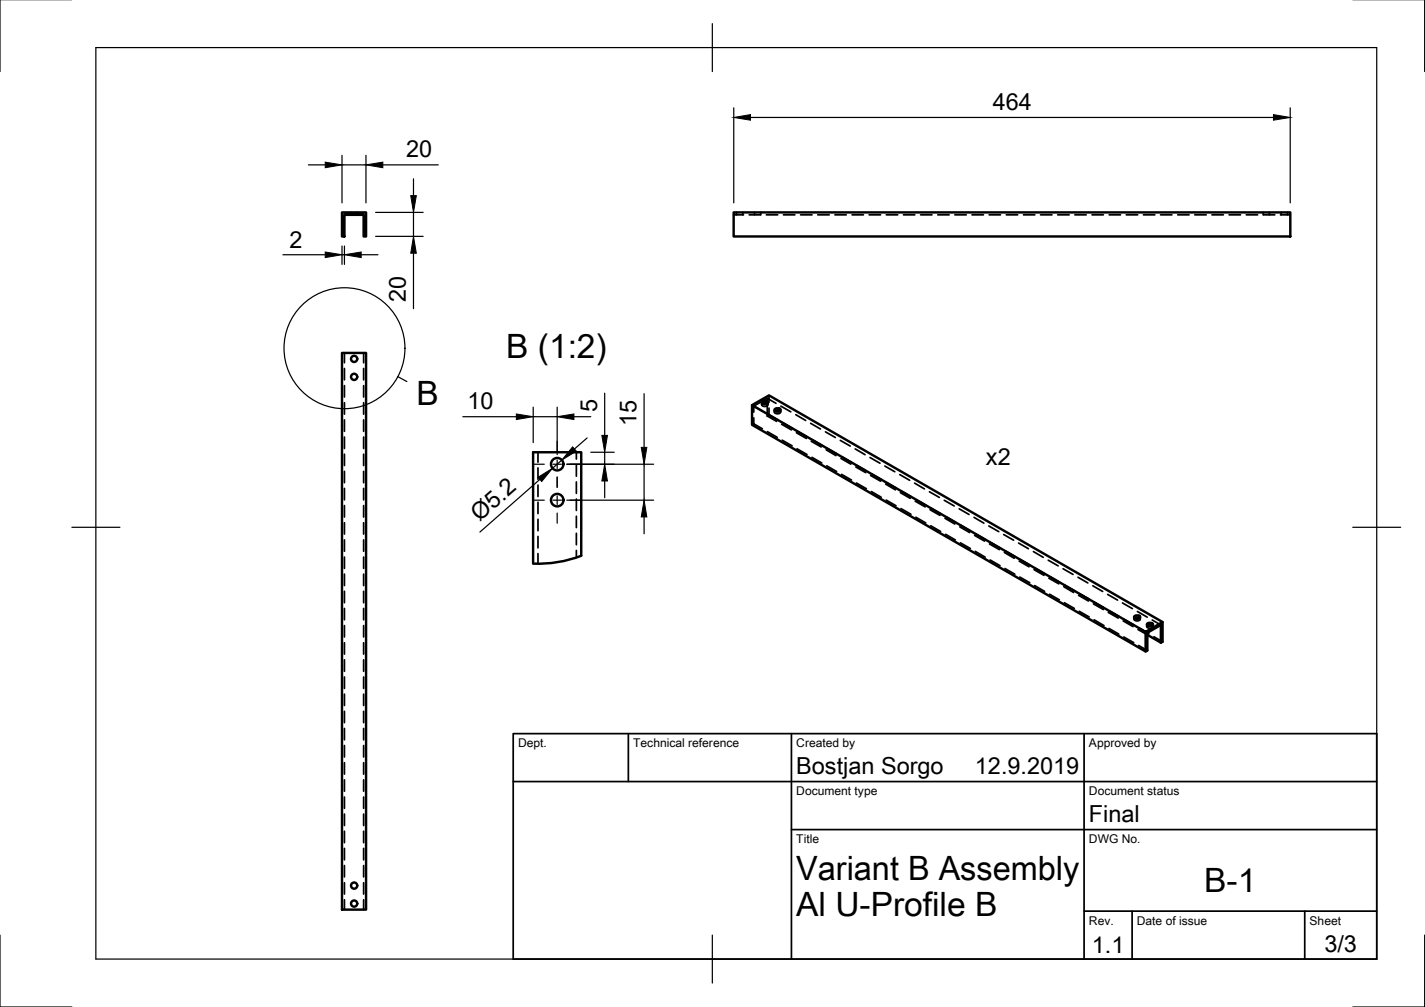
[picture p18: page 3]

Dept. | Technical reference | Created by Bostjan Sorgo 12.9.2019 | Approved by

Document type | Document status Final

Title Al U-Profile B | DWG No. B-1 Variant B Assembly

Rev. | Date of issue | Sheet

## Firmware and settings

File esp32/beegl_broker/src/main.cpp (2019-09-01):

/*
  main.cpp - BeeGl Broker Main Program
  
  This file is part of the BeeGl distribution (https://github.com/bsorgo/beegl).
  Copyright (c) 2019 Bostjan Sorgo
  
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
*/
#undef CONFIG_ARDUHAL_ESP_LOG
#define DEBUG 1

#ifndef ESP32
#error "Only ESP32 supported"
#endif
#include <Arduino.h>
#include <SPI.h>
#include <WiFi.h>

#include <ArduinoNvs.h>
#include <Storage.h>
#include <EEPROM.h>
#include <TimeLib.h>
#include <unistd.h>
#include "esp32-hal-log.h"
#include "Indicator.h"
#include "Service.h"
#include "Settings.h"
#include "Connection.h"

#include "Runtime.h"
#include "Updater.h"
#include "Publisher.h"
#include "HttpPublisher.h"
#include "MqttPublisher.h"
#include "Measurer.h"
#include "SettingsManagement.h"
#include "LogManagement.h"

#include "Broker.h"
#ifdef HEAPTRACE
#include "esp_heap_trace.h"
#define HEAP_TRACE_NUM_RECORDS 100
static heap_trace_record_t trace_record[HEAP_TRACE_NUM_RECORDS]; // This buffer must be in internal RAM
#endif

WiFiClient wifiClient;
Indicator indicator = Indicator();
Settings settings = Settings();
Service service = Service(&settings);
Connection connection = Connection(&settings);
Runtime runtime = Runtime(&service, &settings, &connection);
Updater updater = Updater(&runtime, &service, &settings, &connection);
SettingsManagement settingsManagement = SettingsManagement(&settings, &connection, &service, &runtime);
LogManagement logManagement = LogManagement(&settings, &service);

Publisher *publisher;
Measurer *measurer;
Broker *broker;

void reportStatus()
{
  if (runtime.getSafeMode())
  {
    indicator.reportFail();
  }
  else
  {
    indicator.reportSuccess();
  }
}



bool nvsSetup()
{
  Serial.println("[NVS] Begin NVS");
  if (!NVS.begin())
  {
    Serial.println("[NVS] An Error has occurred while initilizing NVS");
    return false;
  }
  return true;
}

void setup()
{

  Serial.begin(115200);
  while (!Serial)
  {
    ;
  }
  if (!nvsSetup() || !storage_setup())
  {
    indicator.reportFail(1);
    return;
  }
  else
  {
    indicator.reportSuccess(1);
  }
  runtime.initialize();
  runtime.setSafeModeOnRestart(1);

  delay(500);
  Serial.flush();

  runtime.printWakeupReason();

  if (runtime.getSafeMode())
  {
    // start AP and web server only
    settings.outboundMode = 0x0;
    settings.inboundMode = 0x1;
    connection.setup();
    service.setup();
    runtime.setSafeModeOnRestart(0);
    log_i("***************************************");
    log_i("******** SAFE/MAINTENANCE MODE ********");
    log_i("***************************************");
    log_i("Use Wifi device, connect to SSID:%s. By using web browser navigate to http://%s", settings.deviceName, settings.apIp.toString().c_str());
    return;
  }

  if (!settingsManagement.readConfig())
  {
    indicator.reportFail(2);
    runtime.setSafeMode(1);
  }
  else
  {
    indicator.reportSuccess(2);
  }

  log_i("[ESP] Device name: %s ", settings.deviceName);
  log_i("[ESP] Inbound mode: %u ", settings.inboundMode);
  log_i("[ESP] Outbound mode: %u ", settings.outboundMode);

  if (!connection.setup())
  {
    indicator.reportFail(3);
    runtime.deepSleep();
  }
  else
  {
    indicator.reportSuccess(3);
  }

  service.setup();
  settingsManagement.syncTimeAndSettings();
  updater.checkFirmware();

  if (settings.protocol & 0x2)
  {
    publisher = new HttpPublisher(&runtime, &settings, &connection, &service);
  }
  else if (settings.protocol & 0x1)
  {
    publisher = new MqttPublisher(&runtime, &settings, &connection, &service);
  }
  publisher->setup();
  measurer = new Measurer(&runtime, &service, &settings, publisher);
  measurer->setup();
  broker = new Broker(&service, &settings, publisher);
  broker->setup();

  runtime.setSafeModeOnRestart(0);
  settingsManagement.storeLastGood();
  indicator.reportSuccess(4);
  connection.suspend();
  delay(2000);
}

void loop()
{
  reportStatus();
  if (runtime.getSafeMode() && millis() > 600000)
  {
    ESP.restart();
  }

  if (!runtime.getSafeMode())
  {
    runtime.checkOperationalTime();
#ifdef HEAPTRACE
    Serial.printf("B measure: %u/n", ESP.getFreeHeap());
#endif
    measurer->measure();
#ifdef HEAPTRACE
    Serial.printf("A measure, B publish: %u/n", ESP.getFreeHeap());
#endif
    if (!publisher->publish())
    {
      indicator.reportFail(2);
    }
#ifdef HEAPTRACE
    Serial.printf("A publish: %u/n", ESP.getFreeHeap());
#endif
  }
  delay(settings.refreshInterval);
}

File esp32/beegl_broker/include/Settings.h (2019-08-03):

/*
  Settings.h- settings header file
  
  This file is part of the BeeGl distribution (https://github.com/bsorgo/beegl).
  Copyright (c) 2019 Bostjan Sorgo
  
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
  You should have received a copy of the GNU General Public License 
  along with this program. If not, see <http://www.gnu.org/licenses/>.
*/

#ifndef BeescaleSettings_h
#define BeescaleSettings_h

#define CONFIG_BUFFER 2600

#define STR_WEIGHTSENSOR "whtS"
#define STR_WEIGHT "w"
#define STR_WEIGHTUNIT "u"
#define STR_WEIGHTUNITG "g"
#define STR_TEMPSENSOR "tmpS"
#define STR_TEMP "t"
#define STR_TEMPUNIT "u"
#define STR_TEMPUNITC "C"
#define STR_HUMIDITYSENSOR "humS"
#define STR_HUMIDITY "h"
#define STR_HUMIDITYUNIT "u"
#define STR_HUMIDITYUNITPERCENT "pct"
#define STR_DEVICEID "id"
#define STR_REFRESH "refresh"
#define STR_DEVICENAME "id"
#define STR_INBOUNDMODE "inM"
#define STR_OUTBOUNDMODE "outM"
#define STR_DEVICETYPE  "type"
#define STR_WIFISETTINGS "wifiS"
#define STR_WIFISSID "ssid"
#define STR_WIFIPASSWORD "pwd"
#define STR_WIFICUSTOMIP "cip"
#define STR_WIFIIP "ip"
#define STR_WIFIGATEWAY "gw"
#define STR_WIFINETMASK "nmsk"
#define STR_SCALESETTINGS "scaleS"
#define STR_SCALEUNIT "u"
#define STR_SCALEOFFSET "off"
#define STR_SCALEFACTOR "f"
#define STR_APSSID "ssid"
#define STR_APPASSWORD "pwd"
#define STR_APSETTINGS "apS"
#define STR_APIP "ip"
#define STR_APGATEWAY "gw"
#define STR_APNETMASK "nmsk"
#define STR_MQTTSETTINGS "mqttS"
#define STR_MQTTSERVER "server"
#define STR_MQTTPORT "port"
#define STR_MQTTUSERNAME "user"
#define STR_MQTTPASSWORD "pwd"
#define STR_MQTTTOPIC "topic"
#define STR_GPRSSETTINGS "gprsS"
#define STR_GPRSAPN "apn"
#define STR_GPRSUSERNAME "user"
#define STR_GPRSPASSWORD "pwd"
#define STR_RESTARTINTERVAL "restInt"
#define STR_SCHSETTINGS "schS"
#define STR_SCHENTRY "schE"
#define STR_SCHHOURFROM "hf"
#define STR_SCHMINFROM "mf"
#define STR_SCHHOURTO "ht"
#define STR_SCHMINTO "mt"
#define STR_SCHUPDATE "upd"
#define STR_TIMEFORMAT "%04d-%02d-%02dT%02d:%02d:%02d%s"
#define STR_TIME "time"
#define STR_TIMESETTINGS "timeS"
#define STR_TIMESZONE "sZone"
#define STR_TIMEZONE "zone"
#define STR_SETTINGSURL "setUrl"
#define STR_SETTINGSUSERNAME "setUser"
#define STR_SETTINGSPASSWORD "setPwd"
#define STR_MEASURERSETTINGS "mesS"
#define STR_MEASURERWEIGHT "mesW"
#define STR_MEASURERTEMPHUM "mesTh"
#define STR_PUBLISHERSETTINGS "pubS"
#define STR_PUBLISHERPROTOCOL "proto"
#define STR_VER "ver"
#define STR_FW_PREFIX "fwUrl"
#define CONFIG_JSON "/config.json"
#define CONFIG_JSON_DEFAULT "/config_default.json"
#define CONFIG_JSON_LAST_GOOD "/config_last_good.json"
#define CONFIG_JSON_BACKUP "/config_backup.json"
#define CONFIG_JSON_TEMP "/config_temp.json"

#include "Log.h"
#include <Timezone.h>
#include <WiFi.h>

#include <ArduinoJson.h>
#include <ArduinoHttpClient.h>

struct SchEntryType
{
    int schedulerHourFrom;
    int schedulerMinFrom;
    int schedulerHourTo;
    int schedulerMinTo;
    bool updateFromServer;
};

static const char CONFIGJSON[] = CONFIG_JSON;
static const char CONFIGJSONLASTGOOD[] = CONFIG_JSON_LAST_GOOD;
static const char CONFIGJSONTEMP[] = CONFIG_JSON_TEMP;
static const char CONFIGJSONBACKUP[] = CONFIG_JSON_BACKUP;
static const char CONFIGJSONDEFAULT[] = CONFIG_JSON_DEFAULT;

extern const uint8_t index_html_start[] asm("_binary_src_index_html_start");
extern const uint8_t index_html_end[] asm("_binary_src_index_html_end");
class Settings
{
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

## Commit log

2019-07-29 Electronic components list
    [BeeGl_Broker_BOM_rev1.0.xlsx]
2019-08-20 Node red flow for MongoDB
2019-08-28 3d models, drawings & full BOMs
    [BeeGL_Broker_LolinD32Pro_SIM800L_BOM_rev_1.0.xlsx, BeeGL_Broker_Variant_A_BOM_rev1.0.xlsx, BeeGL_Broker_Variant_B_BOM_rev1.0.xlsx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]
2019-08-28 only stl models
    [beegl_broker_case_cover.3mf, beegl_broker_case_cover_no_holes.3mf, beegl_broker_mounting_panel.3mf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]
2019-08-28 Renamed file
    [BeeGl_Broker_Variant_A_BOM_rev1.0.xlsx, BeeGl_Broker_Variant_B_BOM_rev1.0.xlsx]
2019-09-01 Improved modem sleep mode. Fixed #8. Updated BOM.
    [BeeGl_Broker_Variant_A_BOM_rev1.0.xlsx, BeeGl_Broker_Variant_B_BOM_rev1.0.xlsx]
2019-09-12 Drawing corrected to match LR hive ground plan -> rev 1.1
2019-09-12 Reference to rev 1.1
    [BeeGl_Broker_Variant_B_BOM_rev1.0.xlsx]
2019-09-12 Removed revision from filenames
    [BeeGl_Broker_Variant_A_BOM.xlsx, BeeGl_Broker_Variant_B_BOM.xlsx]

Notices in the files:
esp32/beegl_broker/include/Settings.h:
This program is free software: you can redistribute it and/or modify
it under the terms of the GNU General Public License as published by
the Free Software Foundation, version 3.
